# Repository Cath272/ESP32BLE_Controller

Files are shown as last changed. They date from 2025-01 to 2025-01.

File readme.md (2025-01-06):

## Introduction

ESP32BLE_Controller is a ESP32 based project that aimes to make an affortable controller.

The project idea came around when i wanted to incorporate pcb design with a esp32 microcontroller.
The controller uses the [ESP32-BLE-CompositeHID library](https://github.com/Mystfit/ESP32-BLE-CompositeHID) and can be used on any Bluetooth device that can accept xinput devices.

## General description

The player turns on the controller and connects it to a pc/phone and it just works as a XINPUT device and can control any game/sofware that implements the xinput API

### Block diagram


## Hardware Design

### ESP32 Wroom Module
  This project is based on the ESP32-WROOM-32 Module that incorporates an Espressif ESP32 Dual Core 32bit microcontroller with 4MB of Flash Storage, an crystal oscilator, decoupling capacitors and an 2.4Ghz Antena for Wi-Fi and Bluetooth.
  I have chosen this module beacause of it's ease of use, the familiarity i have with it and it low price (around 2.5EUR).  
  
### USB C 14pin port
  USB port for programing and for providing 5V power. It uses 2 5.1K resistors on the CC lines so it can use USB PD and request 5V from it. (Aka use a Type C to Type C cable)
### TPS63020 - High Efficiency Single Inductor Buck-Boost Converter
  Buck Boost Converter that converts 5V from USB to the 3.3V used by the Wroom Module and the CH343p Ic. It also needs an 1.5uH Inductor and filtering caps on the input and output. I chose this Ic because of its High Efficiency. 

### CH343P USB to High-Speed Serial Chip
  USB to High Speed Serial Ic for programming the ESP32. It is made by WCH and i mainly chose it beacause of its small form QFN package and its low price. 

### 10 Buttons
  10 SMD Buttons connected to GPIOs of the ESP32. 
### 2 BC817 Transistors
  2 Transistors used for the auto programming circuit
  
### 2 LEDS (RED for Power and BLUE IO2 configurable)
  
### Schematic:


### Bill of materials 
| Component | Image | Model  | Pcs | Price | Link |
| --- | ---  | ---  | --- | --- | --- |
| ESP32 Wroom Module  |   | ESP32-WROOM-32 | 1 | 2.5EUR | [Aliexpress](https://www.aliexpress.com/item/1005006579469362.html?spm=a2g0o.order_list.order_list_main.5.1cc41802YGhEhy)  |
| USB C 16pin port |  | USB C 16 PIN | 1 | 4.85EUR/100Pcs, 0.05EUR/1Pcs | [Aliexpress](https://www.aliexpress.com/item/1005006072023656.html?spm=a2g0o.order_list.order_list_main.27.1cc41802YGhEhy) |
|Buck Boost Coverter  |  | TPS63020 | 1 | 3.5EU10/Pcs 0.35EUR/Pcs | [Aliexpress](https://www.aliexpress.com/item/1005006228616468.html?spm=a2g0o.order_list.order_list_main.76.1cc41802YGhEhy) |
|USB To Serial | images | CH343P | 1 | 8EUR/10Pcs, 0.8EUR/1Pcs | [Aliexpress](https://www.aliexpress.com/item/1005006879961854.html?spm=a2g0o.order_list.order_list_main.81.1cc41802YGhEhy) | 
|Buttons | Closed | Metal Dome 3.7*3.7*0.35mm | 10 | 1.5EUR/10Pcs | [Aliexpress](https://www.aliexpress.com/item/4001125555481.html?spm=a2g0o.order_list.order_list_main.90.1cc41802YGhEhy) |
|NPN Transistor |  | BC817 | 2 | 1.5EUR/100PCs, 0.015EUR/Pcs | [Aliexpress](https://www.aliexpress.com/item/4001032215515.html?spm=a2g0o.order_list.order_list_main.138.1cc41802YGhEhy) |

Other Components are from Components Sample Books that include many values of [Resistors](https://www.aliexpress.com/item/1005006169072137.html?spm=a2g0o.order_list.order_list_main.185.1cc41802YGhEhy), [LEDs](https://www.aliexpress.com/item/1005003580299883.html?spm=a2g0o.order_list.order_list_main.174.1cc41802YGhEhy) and [Capacitors](https://www.aliexpress.com/item/1005005456060166.html?spm=a2g0o.order_list.order_list_main.178.1cc41802YGhEhy) that i bought before.

###PCB

The PCB was created by me, using KICAD 8.0

Front:



Back:



## Software Design

The program is simple and just reads what buttons are pressed and send the matching XINPUT mapped button through bluetooth to the connected device.
The Program is centered around the [ESP32-BLE-CompositeHID library](https://github.com/Mystfit/ESP32-BLE-CompositeHID) and a specific version of [NimBLE-Arduino](https://github.com/h2zero/NimBLE-Arduino) (Not needed anymore as the CompositeHID library was updated recently).
I used the ESP32-BLE-CompositeHID library because i wanted it to work seamlessly with any windows device, as it just sees it as an Xbox Controller, and windows has xbox controller drivers built in. No need for Steam mapping or any other software.
The Project uses buttons, an led for showing that it conected to the pc and it uses Serial to print any pressed button.

## Results







[Video demonstration](https://storage.rcs-rds.ro/links/72c412c2-119c-4140-a43d-5230902e5003)

## Resources
[ESP32-BLE-CompositeHID library](https://github.com/Mystfit/ESP32-BLE-CompositeHID)

[NimBLE-Arduino](https://github.com/h2zero/NimBLE-Arduino)

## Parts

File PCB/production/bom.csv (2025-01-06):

Designator | Footprint | Quantity | Value | LCSC Part #
BT1 | PinSocket_1x02_P2.54mm_Vertical | 1 | 2x 1.2V NihM AA
C1, C2 | 0805 | 2 | 22uF
C10, C3 | 0402 | 2 | 0.1uF
C4, C5 | 0402 | 2 | 1uF
C7 | CP_EIA-3528-15_AVX-H_Pad1.50x2.35mm_HandSolder | 1 | 100uF 6.3V
D1, D3 | 0603 | 2 | LED
J1 | USB_C_Receptacle_GCT_USB4105-xx-A_16P_TopMnt_Horizontal | 1 | USB_C_Receptacle_USB2.0_16P
L1 | L_6.3x6.3_H3 | 1 | 1.5uH
Q1, Q2 | SOT-23 | 2 | BC817
Q3 | TSOT-23_HandSoldering | 1 | PMOS
R1 | 0402 | 1 | 1.5k
R10, R12, R4, R5 | 0402 | 4 | 10K
R11, R13, R15 | 0402 | 3 | 470
R16 | 0402 | 1 | 1M
R17 | 0402 | 1 | 180k
R2, R3 | 0402 | 2 | 5.1k
S1 | 430173003816 | 1 | X Button
S10 | 430173003816 | 1 | Left
S2 | 430173003816 | 1 | A Button
S3 | 430173003816 | 1 | B Button
S4 | 430173003816 | 1 | Y button
S5 | 430173003816 | 1 | Start Button
S6 | 430173003816 | 1 | Select Button
S7 | 430173003816 | 1 | UP
S8 | 430173003816 | 1 | Right
S9 | 430173003816 | 1 | Down
SW1 | SW_Tactile_SKHH_Angled | 1 | R Button
SW2, SW3 | SW_SPST_PTS810 | 2 | SW_Push
SW4 | SW_Tactile_SKHH_Angled | 1 | L Button
U1 | ESP32-WROOM-32D | 1 | ESP32-WROOM-32D
U3 | TQFN-16-1EP_3x3mm_P0.5mm_EP1.6x1.6mm | 1 | CH343P
U4 | QFN14-3X4MM | 1 | TPS63020

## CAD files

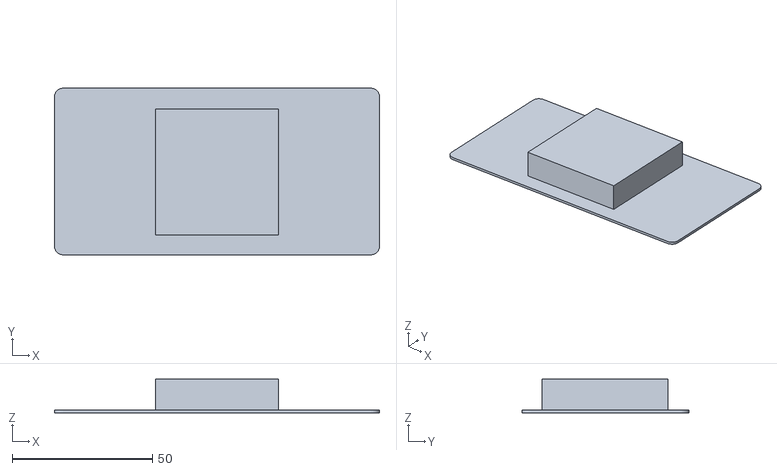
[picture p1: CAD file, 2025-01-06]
3d_models/back.stl
116.0 x 59.5 x 12.0

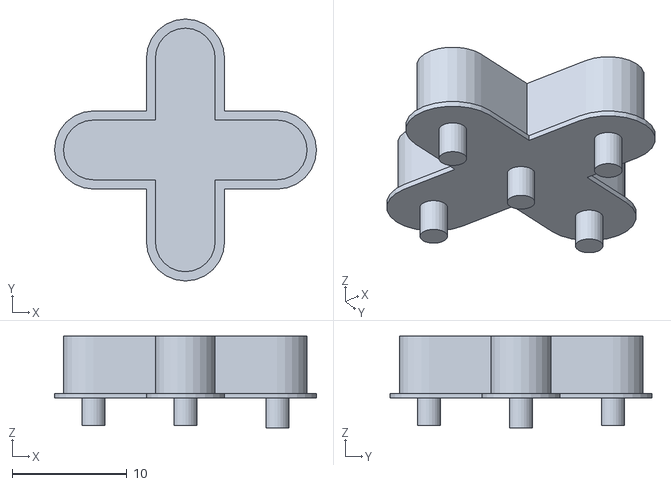
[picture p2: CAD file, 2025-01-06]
3d_models/dpad_3d.stl
22.8 x 22.8 x 8.00

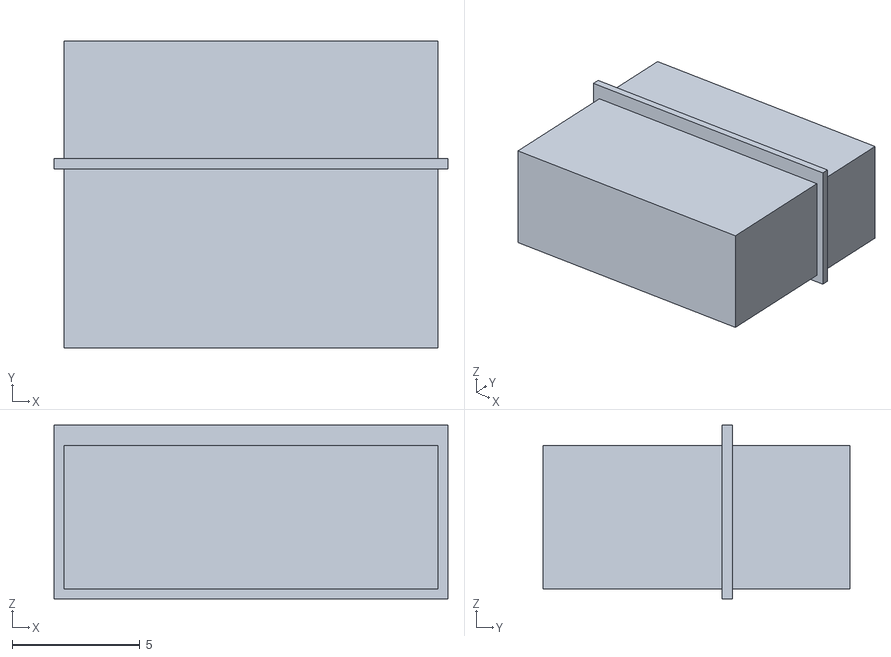
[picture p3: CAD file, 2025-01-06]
3d_models/Shoulder_btn3d.stl
15.4 x 12.0 x 6.80

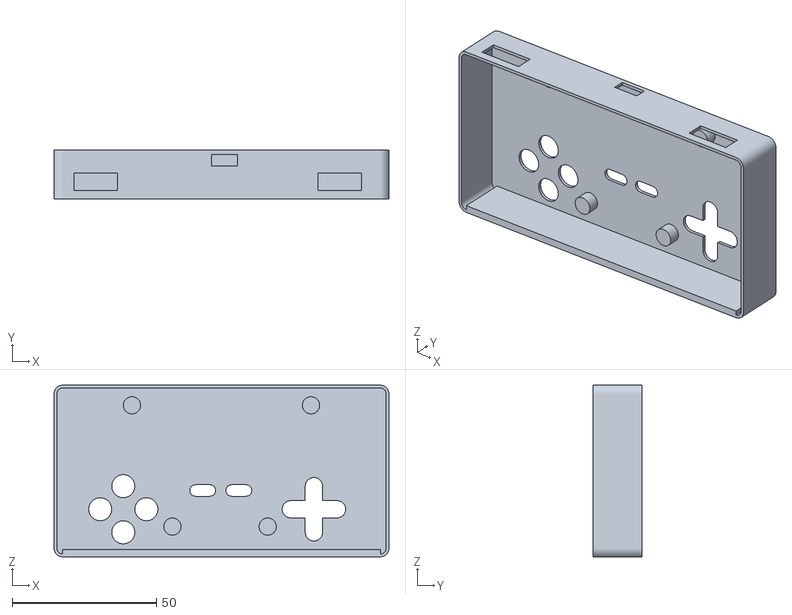
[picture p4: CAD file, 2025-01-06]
3d_models/controller_3d.stl
116.0 x 17.0 x 59.5

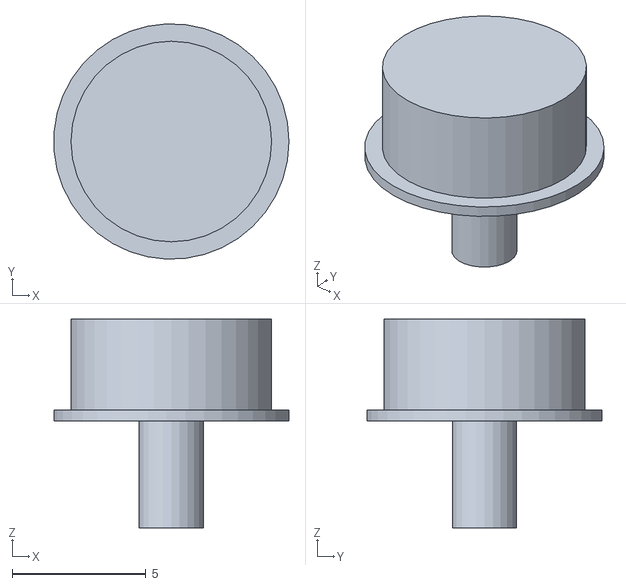
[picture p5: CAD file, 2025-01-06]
3d_models/button_3d.stl
8.79 x 8.79 x 7.80

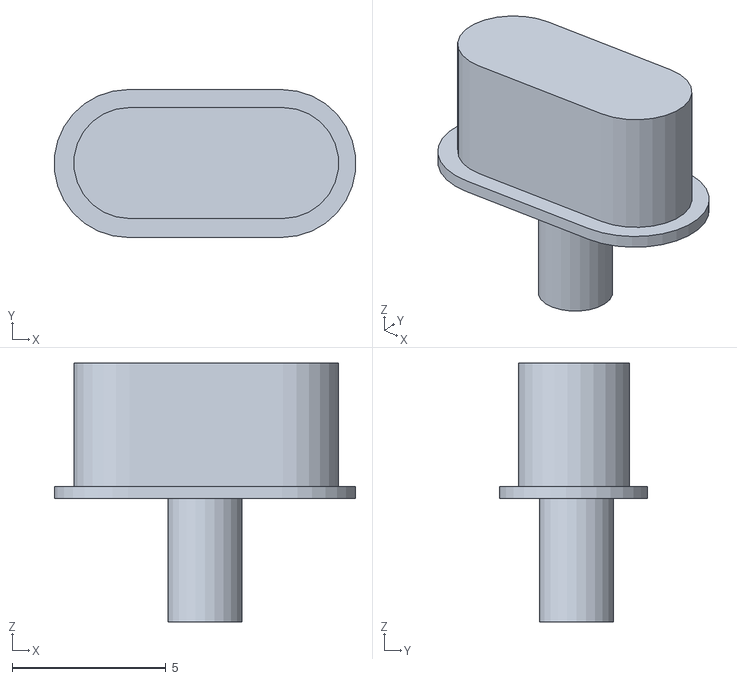
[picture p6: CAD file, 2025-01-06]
3d_models/option_3d.stl
9.77 x 4.80 x 8.40

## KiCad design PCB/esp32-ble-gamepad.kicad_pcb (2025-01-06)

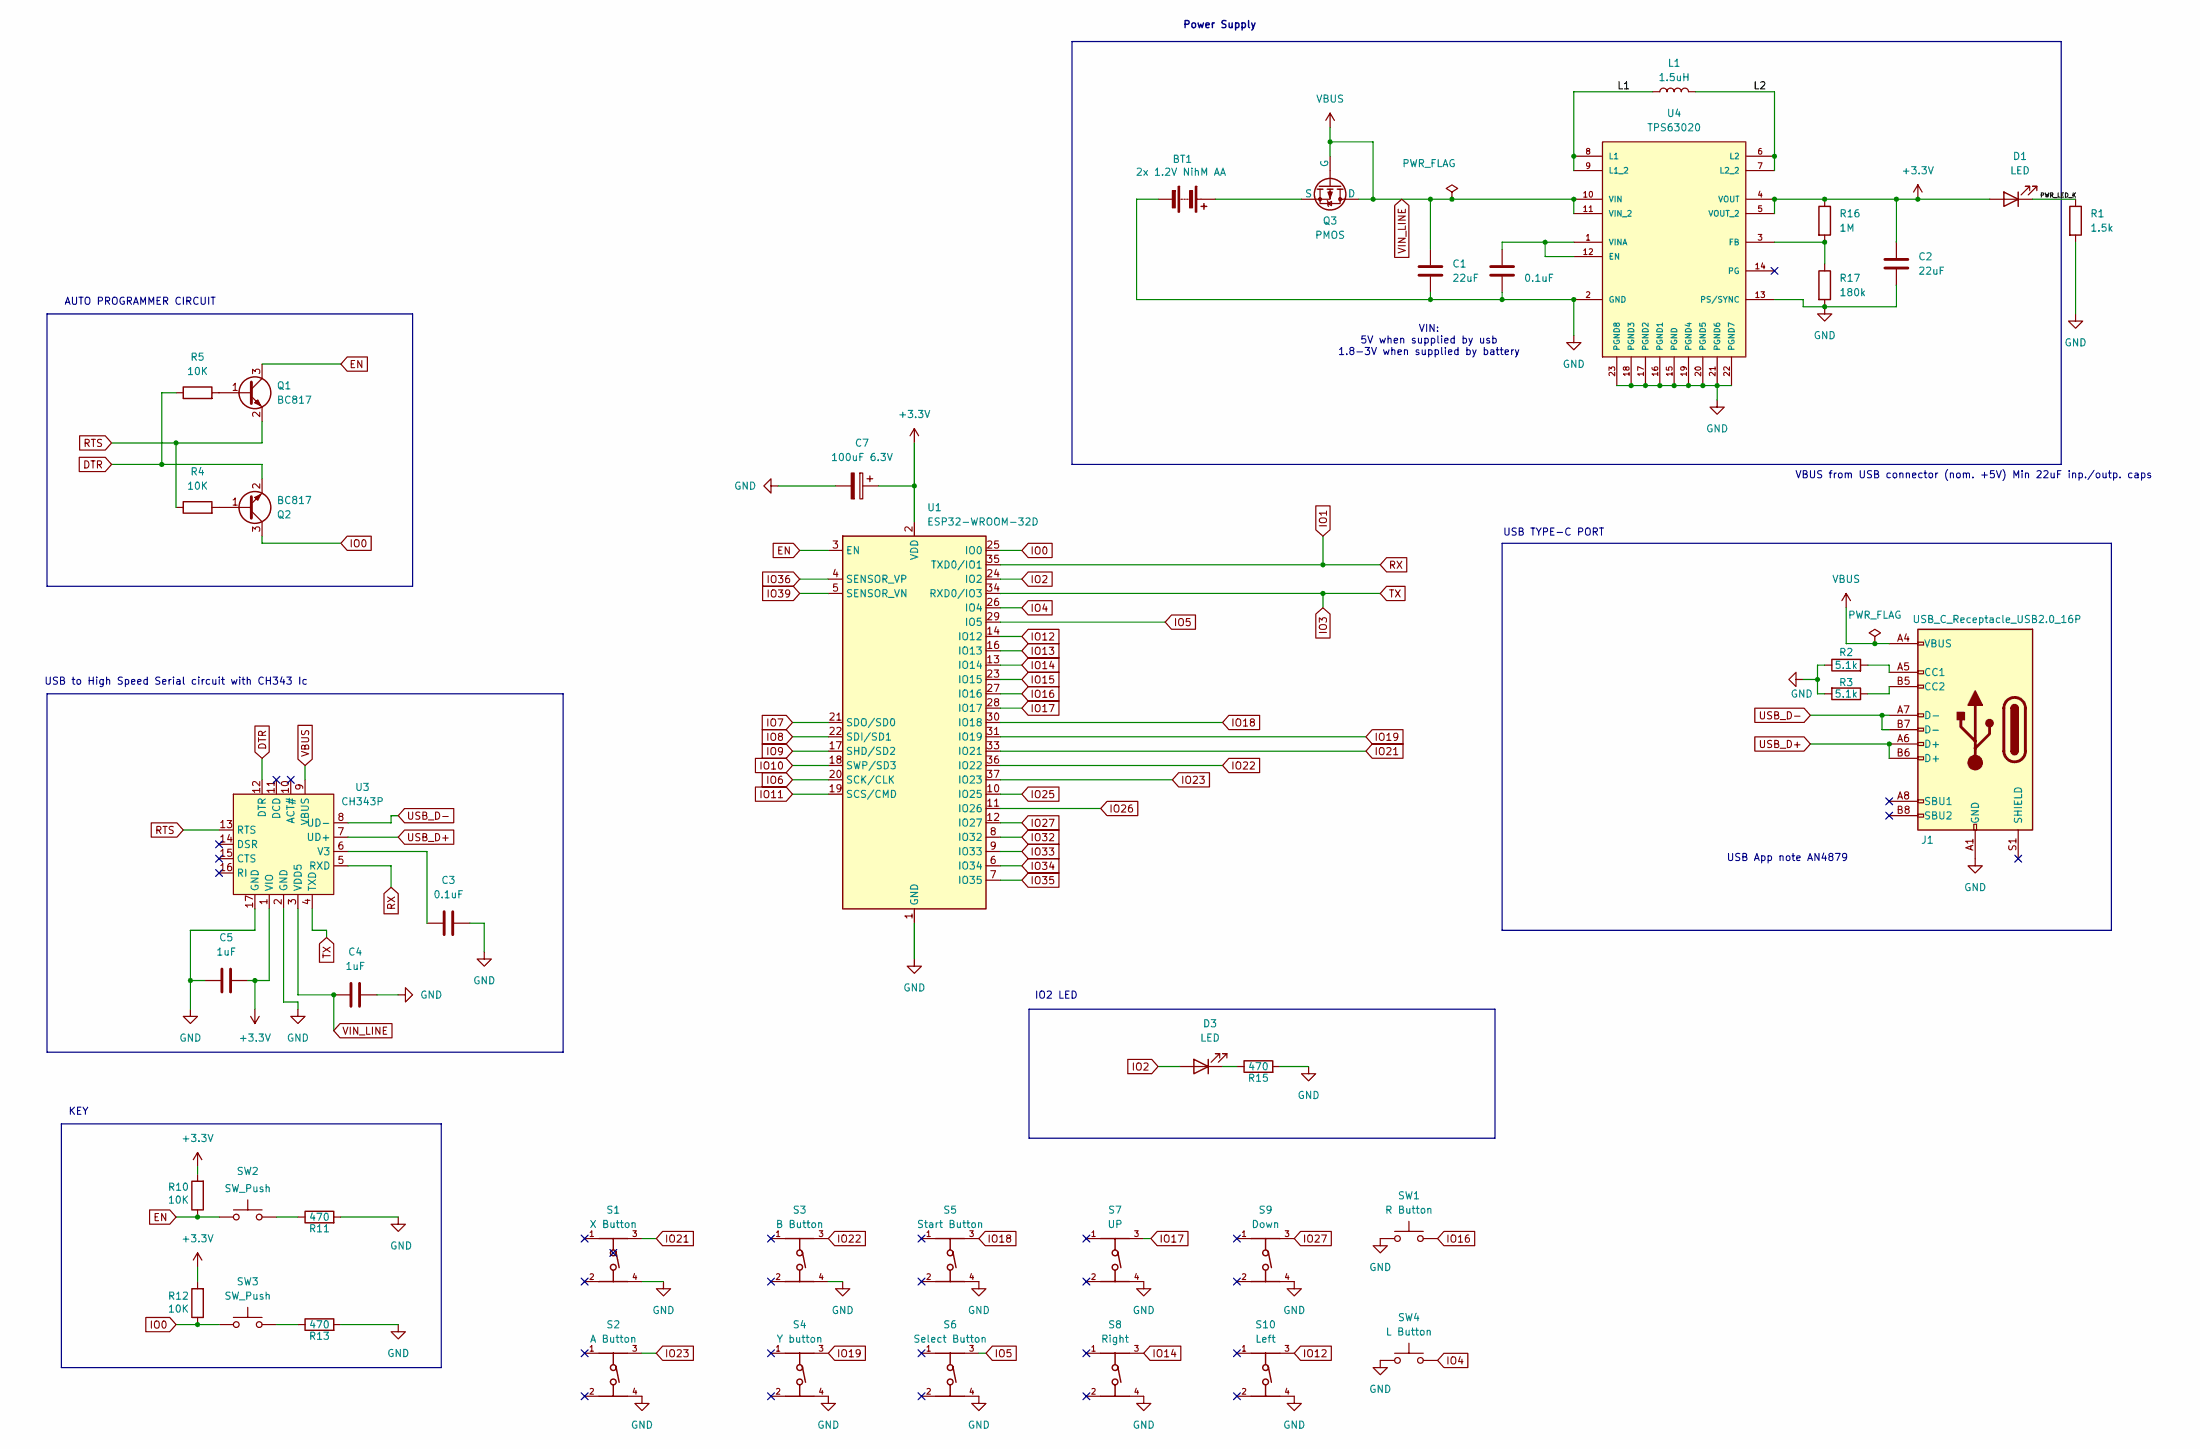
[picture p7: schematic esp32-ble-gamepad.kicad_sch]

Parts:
BT1: 2x 1.2V NihM AA; PinSocket_1x02_P2.54mm_Vertical
C1, C2: 22uF; C_0805_2012Metric
C3, C10: 0.1uF; C_0402_1005Metric
C4, C5: 1uF; C_0402_1005Metric
C7: 100uF 6.3V; CP_EIA-3528-15_AVX-H_Pad1.50x2.35mm_HandSolder
D1, D3: LED; LED_0603_1608Metric
J1: USB_C_Receptacle_USB2.0_16P; USB_C_Receptacle_GCT_USB4105-xx-A_16P_TopMnt_Horizontal
L1: 1.5uH; L_6.3x6.3_H3
Q1, Q2: BC817; SOT-23
Q3: PMOS; TSOT-23_HandSoldering
R1: 1.5k; R_0402_1005Metric
R2, R3: 5.1k; R_0402_1005Metric
R4, R5, R10, R12: 10K; R_0402_1005Metric
R11, R13, R15: 470; R_0402_1005Metric
R16: 1M; R_0402_1005Metric
R17: 180k; R_0402_1005Metric
S1: X Button; 430173003816; PART-NUMBER 430173003816
S2: A Button; 430173003816; PART-NUMBER 430173003816
S3: B Button; 430173003816; PART-NUMBER 430173003816
S4: Y button; 430173003816; PART-NUMBER 430173003816
S5: Start Button; 430173003816; PART-NUMBER 430173003816
S6: Select Button; 430173003816; PART-NUMBER 430173003816
S7: UP; 430173003816; PART-NUMBER 430173003816
S8: Right; 430173003816; PART-NUMBER 430173003816
S9: Down; 430173003816; PART-NUMBER 430173003816
S10: Left; 430173003816; PART-NUMBER 430173003816
SW1: R Button; SW_Tactile_SKHH_Angled
SW2, SW3: SW_Push; SW_SPST_PTS810
SW4: L Button; SW_Tactile_SKHH_Angled
U1: ESP32-WROOM-32D
U3: CH343P; TQFN-16-1EP_3x3mm_P0.5mm_EP1.6x1.6mm
U4: TPS63020; QFN14-3X4MM

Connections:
+3.3V: C2.1, C5.2, C7.1, D1.2 (A), R10.2, R12.2, R16.1, U1.2 (VDD), U3.1 (VIO), U4.4 (VOUT), U4.5 (VOUT_2)
/L1: L1.1, U4.8 (L1), U4.9 (L1_2)
/L2: L1.2, U4.6 (L2), U4.7 (L2_2)
/PWR_LED_K: D1.1 (K), R1.1
DTR: Q2.2 (E), R5.1, U3.12 (DTR)
EN: Q1.3 (C), R10.1, SW2.1, U1.3 (EN)
GND: BT1.2 (-), C1.2, C2.2, C3.2, C4.2, C5.1, C7.2, C10.1, J1.A1 (GND), J1.A12 (GND), J1.B1 (GND), J1.B12 (GND), R1.2, R2.1, R3.2, R11.2, R13.2, R15.2, R17.2, S1.4, S2.4, S3.4, S4.4, S5.4, S6.4, S7.4, S8.4, S9.4, S10.4, SW1.1, SW4.1, U1.1 (GND), U1.15 (GND), U1.38 (GND), U1.39 (GND), U3.2 (GND), U3.17 (GND), U4.2 (GND), U4.13 (PS/SYNC), U4.15 (PGND), U4.16 (PGND1), U4.17 (PGND2), U4.18 (PGND3), U4.19 (PGND4), U4.20 (PGND5), U4.21 (PGND6), U4.22 (PGND7), U4.23 (PGND8)
IO0: Q2.3 (C), R12.1, SW3.1, U1.25 (IO0)
IO1: U1.35 (TXD0/IO1), U3.5 (RXD)
IO2: D3.2 (A), U1.24 (IO2)
IO3: U1.34 (RXD0/IO3), U3.4 (TXD)
IO4: SW4.2, U1.26 (IO4)
IO5: S6.3, U1.29 (IO5)
IO6: U1.20 (SCK/CLK)
IO7: U1.21 (SDO/SD0)
IO8: U1.22 (SDI/SD1)
IO9: U1.17 (SHD/SD2)
IO10: U1.18 (SWP/SD3)
IO11: U1.19 (SCS/CMD)
IO12: S10.3, U1.14 (IO12)
IO13: U1.16 (IO13)
IO14: S8.3, U1.13 (IO14)
IO15: U1.23 (IO15)
IO16: SW1.2, U1.27 (IO16)
IO17: S7.3, U1.28 (IO17)
IO18: S5.3, U1.30 (IO18)
IO19: S4.3, U1.31 (IO19)
IO21: S1.3, U1.33 (IO21)
IO22: S3.3, U1.36 (IO22)
IO23: S2.3, U1.37 (IO23)
IO25: U1.10 (IO25)
IO26: U1.11 (IO26)
IO27: S9.3, U1.12 (IO27)
IO32: U1.8 (IO32)
IO33: U1.9 (IO33)
IO34: U1.6 (IO34)
IO35: U1.7 (IO35)
IO36: U1.4 (SENSOR_VP)
IO39: U1.5 (SENSOR_VN)
unnamed: BT1.1 (+), Q3.2 (S)
unnamed: D3.1 (K), R15.1
unnamed: J1.A5 (CC1), R2.2
unnamed: J1.B5 (CC2), R3.1
unnamed: Q1.1 (B), R5.2
unnamed: Q2.1 (B), R4.2
unnamed: R11.1, SW2.2
unnamed: R13.1, SW3.2
unnamed: C3.1, U3.6 (V3)
unnamed: C10.2, U4.1 (VINA), U4.12 (EN)
unnamed: R16.2, R17.1, U4.3 (FB)
RTS: Q1.2 (E), R4.1, U3.13 (RTS)
USB_D+: J1.A6 (D+), J1.B6 (D+), U3.7 (UD+)
USB_D-: J1.A7 (D-), J1.B7 (D-), U3.8 (UD-)
VBUS: C1.1, C4.1, J1.A4 (VBUS), J1.A9 (VBUS), J1.B4 (VBUS), J1.B9 (VBUS), Q3.1 (G), Q3.3 (D), U3.3 (VDD5), U3.9 (VBUS), U4.10 (VIN), U4.11 (VIN_2)

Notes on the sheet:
KEY
IO2 LED
USB to High Speed Serial circuit with CH343 Ic
AUTO PROGRAMMER CIRCUIT
VIN: 5V when supplied by usb 1.8-3V when supplied by battery
VBUS from USB connector (nom. +5V) Min 22uF inp./outp. caps
USB App note AN4879
Power Supply
USB TYPE-C PORT

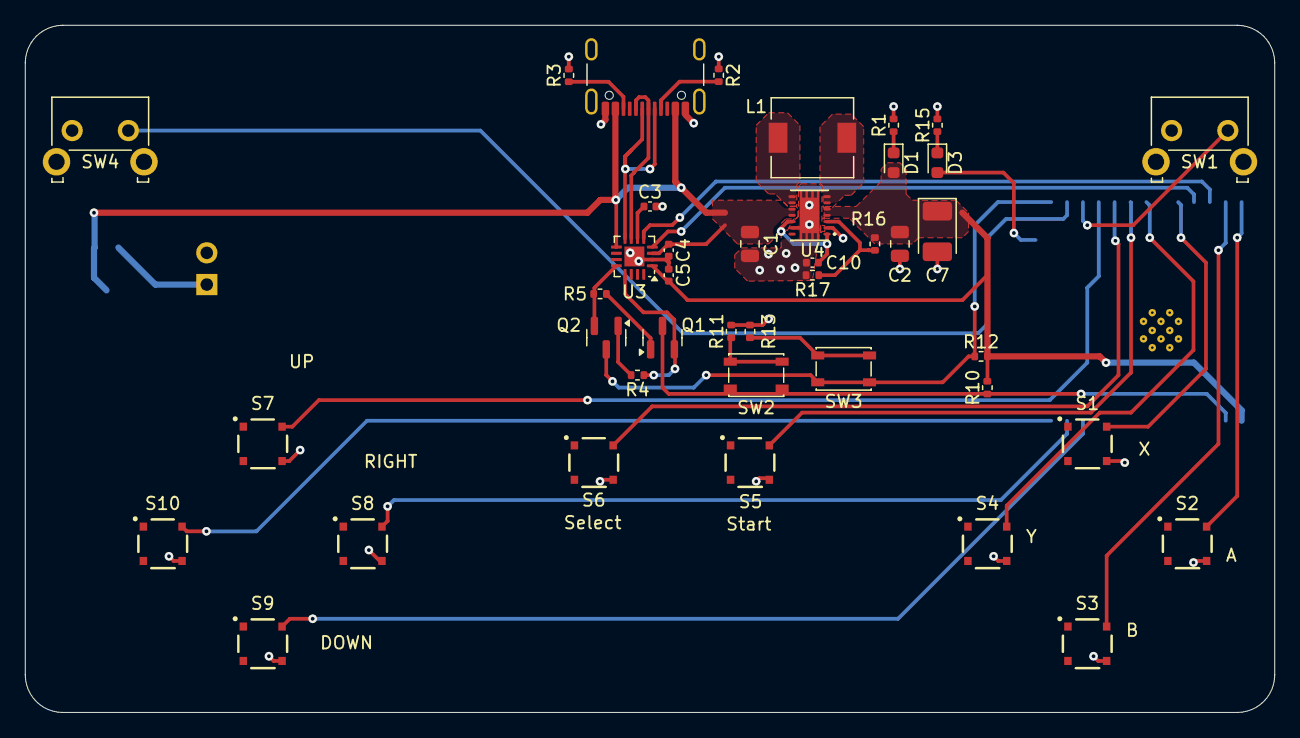
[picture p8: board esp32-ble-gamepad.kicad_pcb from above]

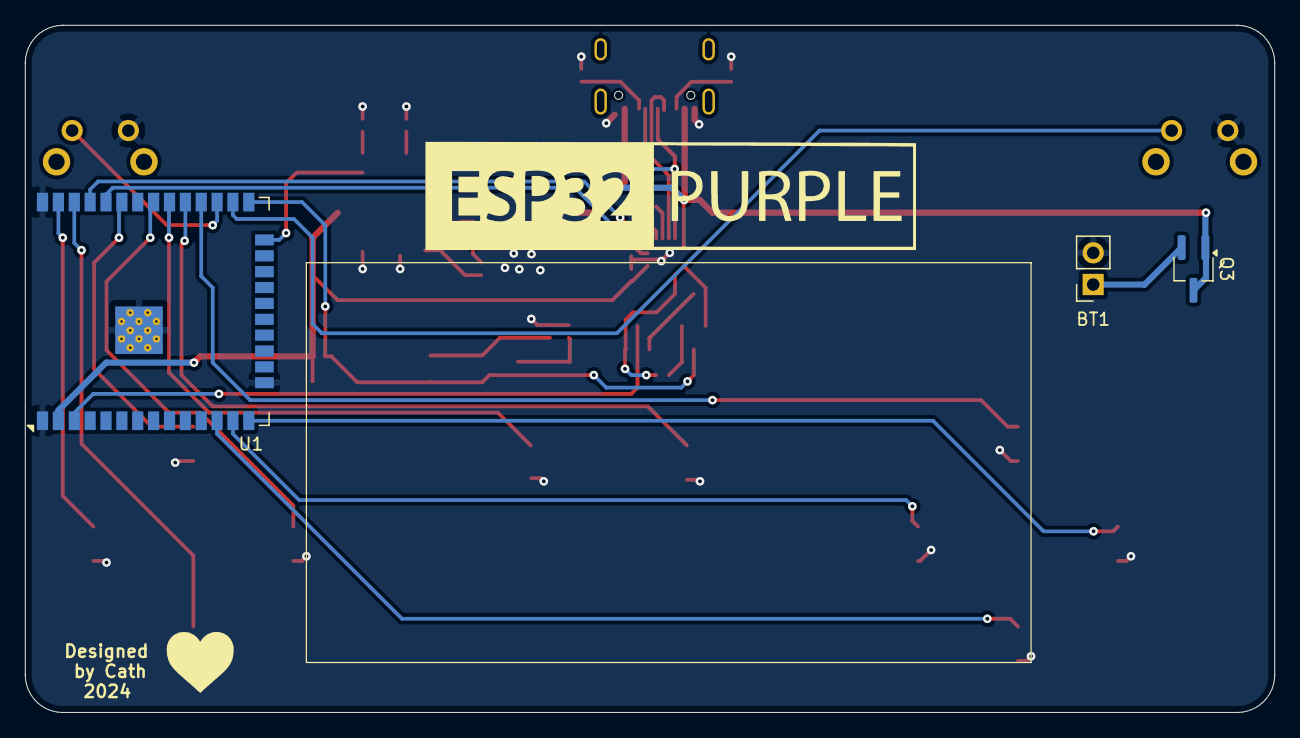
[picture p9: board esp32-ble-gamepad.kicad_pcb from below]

Board: 2 copper layers, 100.0 x 55.0 mm, 44 parts (3 on the bottom side), 38 nets.
